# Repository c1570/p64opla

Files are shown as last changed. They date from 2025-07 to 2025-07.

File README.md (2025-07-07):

# p64oPLA - microcontroller-based C64 PLA
https://github.com/c1570/p64opla

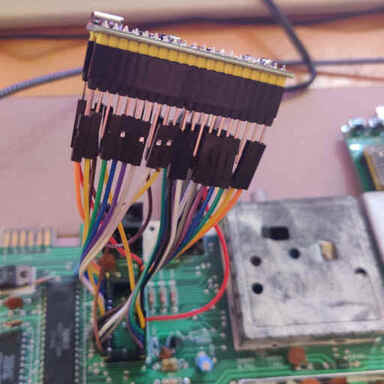
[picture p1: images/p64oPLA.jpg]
p64oPLA prototype


This implements the [Commodore 64](https://en.wikipedia.org/wiki/Commodore_64) [PLA chip](https://www.c64-wiki.com/wiki/PLA_(C64_chip)) using an [RP2040](https://en.wikipedia.org/wiki/RP2040).

This is work in progress.

Pronounced **picoPLA**. Stylizing as 'p64oPLA' makes this better to search for, and it's not really using the Pico (board) anyways.

* cheap
* simple hardware variant can be built using a spare IC socket and a few wires
* extra modes
  * **selftest** (GPIO26 grounded): Checks for shorts on GPIO pins, blinks GPIO num+1 times (GPIO2 = 3 flashes) in case of problems on that line. If no error found, turns LED on for five seconds, off for 100ms, repeat.
  * **offline PLA test** (GPIO26 and GPIO24 grounded): Checks a PLA connected in parallel for errors. LED will blink on errors. If no error found, turns LED on for five seconds, off for 100ms, repeat. Problems as well as **measured CASRAM latency** will be reported in text via USB serial.
  * **live PLA test** (GPIO24 grounded): If connected to a PLA seated in a C64, will check those PLA's outputs while the C64 is powered on. Make sure p64oPLA is not connected via USB then (otherwise current would flow from USB into the C64). LED will light on errors, otherwise the LED will stay off.

* Line delay is very similar to the original PLA.
* In contrast to most replacements, all signal lines exhibit the appropriate signal delay, not only CASRAM.
* There are no glitches (EPROM PLA, I'm looking at you).
* However, this implementation exhibits some delay jitter (signal delay is about 30-42ns).

# Building

* wiring the RP2040 board and PLA
  * connect GPIO0-7 to PLA pins 2-9
  * connect GPIO8-15 to PLA pins 20-27
  * connect GPIO16-19 to PLA pins 10-13
  * connect GPIO20-23 to PLA pins 15-18
  * connect 5V/Vbus to PLA pin 28
  * connect GND to PLA pin 14 and PLA pin 19
  * leave PLA pin 1 unconnected
* note the original Pico board does not expose GPIO23; "RGB LED" RP2040 boards do though (disable the RGB LED there though by unsoldering the "RGB" jumper)

## PCB

Designing a dedicated PCB would be nice at some point...

## Test clips

For the live test mode, you'll want some way to connect 26 wires (PLA pin 19 is not needed then) to the PLA in the C64 reliably which can be arduous.
You can 3D print [dip_clip_28p.stl](/hardware/dip_clip_28p.stl) twice and build an 28 pin DIP test clip from that.
The STL file has been generated from ["DIP IC Test Clip"](https://www.thingiverse.com/thing:4690158/) by Andy Anderson (CC-BY license) using settings `ic_pin_count = 28` and `ic_width = 14`.

# Implementation notes
This simply looks up output values using an array using the CPU cores, overclocked to 400MHz.
Both cores run in parallel, executing the same program, to reduce worst case latency.
They sync automatically because of SRAM lookup contention.

The data word read from the GPIOs represents the RAM address of the byte to look up directly because input overrides are set for upper GPIOs.

No shifting of the output value (to GPIO16 and up) is needed since byte writes to SIO registers are replicated over the full bus width (e.g., writing byte 0x12 actually writes 0x12121212).

## Abandoned PIO/DMA version
A PIO/DMA variant of this was also in testing (similar to [cknave's C64 Pico RAM interface](https://github.com/cknave/c64-pico-ram-interface)):

* reading from GPIOs using a PIO
* DMA the resulting address from the PIO RX FIFO to another DMA channel's read address (and trigger) register
* The other DMA channel fetches the result byte from the lookup table and writes it to another PIO
* Other PIO writes to GPIOs

(One could actually omit using the PIOs but unfortunately SIO GPIO control registers are only available to the CPU cores, not DMA.)

However, this has a rather long latency along these lines:
* 1 cycle input GPIO pad
* 2 cycles input synchronizer
* 1 cycle input PIO
* 4 cycles first DMA pipeline (details: [1](https://forums.raspberrypi.com/viewtopic.php?p=1915671#p1915671) [2](https://forums.raspberrypi.com/viewtopic.php?p=2196725#p2196725) [3](https://forums.raspberrypi.com/viewtopic.php?p=2247708#p2247708))
* 4 cycles second DMA pipeline
* 1 cycle output PIO
* 1 cycle output GPIO pad

Also, there's a lot of jitter, probably because PIO FIFO reads/writes and DMA control writes all go through a single AHB port.

Perhaps RP2350 improves this, but I doubt it.

# License
AGPLv3

In short, this means that...
* proper attribution has to be given
* source has to be made available

In case you don't want to do this (e.g., you want to sell white labeled versions commercially, or not hand out the sources, or similar), commercial licenses are available starting 20€/piece.

# Compiling
```
export PICO_SDK_PATH=...
cmake -DPICO_COPY_TO_RAM=1 .
make -j16
```

## Testing
Use `src/test-p64pla.ts` along with [rp2040js](https://github.com/c1570/rp2040js).

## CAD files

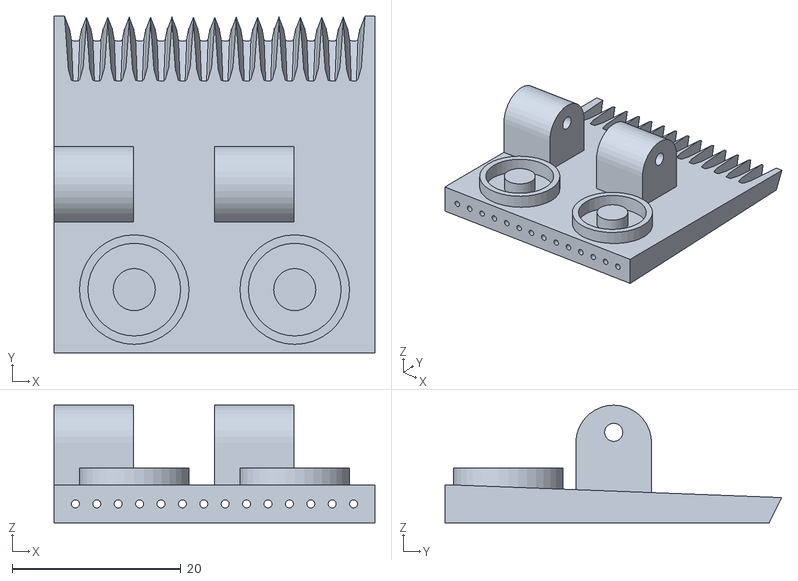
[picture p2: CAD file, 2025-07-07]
hardware/dip_clip_28p.stl
38.1 x 40.0 x 14.0

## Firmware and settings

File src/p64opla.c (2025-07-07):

// p64oPLA - microcontroller-based C64 PLA
// https://github.com/c1570/p64opla
// AGPLv3 licensed

#include <stdio.h>
#include "pico/stdlib.h"
#include "pico/sync.h"
#include "pico/multicore.h"
#include "hardware/pio.h"
#include "hardware/vreg.h"
#include "hardware/clocks.h"
#include "hardware/structs/sio.h"

#include "pla.h"

uint SYS_CLOCK_KHZ = 400000;

const uint LED_PIN = 25;
const uint BUTTON_PIN = 24;
const uint MODE_PIN = 26;

void blink_led(const uint flashes, const uint on_ms, const uint off_ms, const uint after_ms) {
  for(uint i = 1; i <= flashes; i++) {
    gpio_put(LED_PIN, 1);
    busy_wait_us(on_ms * 1000);
    gpio_put(LED_PIN, 0);
    busy_wait_us(off_ms * 1000);
  }
  busy_wait_us(after_ms * 1000);
}

static void selftest(const uint pin_start, const uint pin_end) {
  // short/stuck detection: sets all pins to pullup, shifts one LOW through pins,
  // blinks if more than one pin is low during that
  gpio_put(LED_PIN, 0);
  gpio_set_dir(LED_PIN, GPIO_OUT);
  for(uint pin = pin_start; pin <= pin_end; pin++) {
    gpio_init(pin);
    gpio_set_dir(pin, GPIO_IN);
    gpio_pull_up(pin);
    gpio_put(pin, false);
  }
  const uint32_t mask_our_pins = ((1 << (pin_end + 1)) - 1) - ((1 << pin_start) - 1);
  while(1) {
    bool found_error = false;
    for(uint pin = pin_start; pin <= pin_end; pin++) {
      gpio_set_dir(pin, GPIO_OUT); // set GPIO "pin" low (value has been set above)
      busy_wait_us(1000);
      uint32_t gpios_in = gpio_get_all() & mask_our_pins;
      if(gpios_in != (mask_our_pins - (1 << pin))) {
        // we expected only one GPIO low but don't see that: there's some short
        blink_led(pin + 1, 500, 200, 800); // start signaling with output pin number
        for(uint test = 0; test <= pin_end; test++) {
          if(test != pin) {
            if(!(gpios_in & 1)) blink_led(test + 1, 500, 200, 800); // blink 1 time for GPIO 0, etc.
            found_error = true;
          }
          gpios_in >>= 1;
        }
        busy_wait_us(2000000);
      }
      gpio_set_dir(pin, GPIO_IN);
    }
    if(!found_error) {
      blink_led(1, 5000, 100, 0);
    } else {
      gpio_put(LED_PIN, 0);
      busy_wait_us(4000000);
    }
  }
}

static void platest_live() {
  // live external PLA test: connect p64opla parallel to another PLA in the C64,
  // run this test, and LED will light if the other PLA behaves incorrectly.
  gpio_put(LED_PIN, 0);
  gpio_set_dir(LED_PIN, GPIO_OUT);
  for(uint pin = 0; pin <= 23; pin++) {
    gpio_init(pin);
    gpio_put(pin, 0);
    gpio_set_dir(pin, GPIO_IN);
  }
  uint32_t steady = 0;
  uint32_t gpios_prev = 0;
  while(1) {
    uint32_t gpios = gpio_get_all() & 0x00ffffff;
    if((gpios & 0xffff) != (gpios_prev & 0xffff)) {
      steady = 0;
      gpios_prev = gpios;
      continue;
    }
    if(steady > 2) {
      // if input lines have been steady for a bit, we can assume
      // outputs have settled as well
      uint8_t expected_out = PLA_OUTPUT[gpios & 0xffff];
      if(((gpios >> 16) & 0xff) != expected_out) {
        gpio_put(LED_PIN, 1);
        busy_wait_us(5000000);
      }
      gpio_put(LED_PIN, 0);
    } else {
      steady++;
    }
  }
}

static inline int __attribute__((always_inline)) get_signal_latency(uint trigger_pin, uint measure_pin, bool trigger_on_posedge, bool wait_for_posedge) {
  // set up pin states in PIO before switching GPIO functions to PIO
  pio_sm_set_consecutive_pindirs(pio0, 0, trigger_pin, 1, true);
  pio_sm_set_pins(pio0, 0, (!trigger_on_posedge) << trigger_pin);
  pio_sm_set_consecutive_pindirs(pio0, 0, measure_pin, 1, false);
  // save previous pin functions, then switch functions to PIO
  enum gpio_function func_trigger = gpio_get_function(trigger_pin);
  gpio_set_function(trigger_pin, GPIO_FUNC_PIO0);
  enum gpio_function func_measure = gpio_get_function(measure_pin);
  gpio_set_function(measure_pin, GPIO_FUNC_PIO0);
  busy_wait_us(10); // wait for things to settle

  pio0->instr_mem[0] = pio_encode_set(pio_pins, trigger_on_posedge);
  pio0->instr_mem[1] = pio_encode_in(pio_pins, 1);
  pio_sm_config measure_sm_config = pio_get_default_sm_config();
  sm_config_set_wrap(&measure_sm_config, 1, 1); // loop on IN instruction
  sm_config_set_in_pins(&measure_sm_config, measure_pin);
  sm_config_set_in_shift(&measure_sm_config, false /* true: shift ISR right */,
                         true /* autopush */, 32 /* autopush threshold */);
  sm_config_set_set_pins(&measure_sm_config, trigger_pin, 1);
  sm_config_set_clkdiv(&measure_sm_config, 1);
  pio_sm_init(pio0, 0, 0 /* SM start instruction addr */, &measure_sm_config);
  pio_sm_set_enabled(pio0, 0, true);

  int cycles = 0;
  while(1) {
    uint32_t p = pio_sm_get_blocking(pio0, 0);
    if(!wait_for_posedge) p = ~p;
    if(__builtin_expect(!p, 1)) { // fast path has to be faster than 32 cycles
      cycles += 32;
      if(cycles >> 22) { // timeout after about 10ms
        cycles = -1;
        break;
      }
      continue;
    } else {
      cycles += __builtin_clz(p); // count leading zero bits
      break;
    }
  }

  pio_sm_set_enabled(pio0, 0, false);
  pio_sm_clear_fifos(pio0, 0);
  // restore previous GPIO functions (SIO in this case)
  gpio_set_function(trigger_pin, func_trigger);
  gpio_set_function(measure_pin, func_measure);
  busy_wait_us(2);

  return cycles;
}

static void platest_offline() {
  // external PLA test: connect p64opla parallel to another PLA standalone,
  // run this test, and LED will light if the other PLA behaves incorrectly.
  // one successful test run takes a few milliseconds.
  gpio_put(LED_PIN, 0);
  gpio_set_dir(LED_PIN, GPIO_OUT);
  for(uint pin = 0; pin <= 23; pin++) {
    gpio_init(pin);
    if(pin < 16) {
      gpio_put(pin, 0);
      gpio_set_dir(pin, GPIO_OUT);
      gpio_set_drive_strength(pin, GPIO_DRIVE_STRENGTH_4MA);
    } else {
      gpio_set_dir(pin, GPIO_IN);
    }
  }
  stdio_init_all();
  while(1) {
    gpio_put_masked(0xffff, 0 | (1<<7) | (1<<14)); // $0000 RAM read access, CAS inactive, BA active
    float lat_min = -1;
    float lat_max = -1;
    for(uint i = 0; i < 10; i++) {
      int latency = get_signal_latency(7, 23, false, false); // enable CAS, wait for CASRAM to go active
      if(latency < lat_min || lat_min == -1) lat_min = latency;
      if(latency > lat_max || lat_max == -1) lat_max = latency;
    }
    // at 400MHz, RP2040 pin to pin latency is 5 cycles
    lat_min = lat_min >= 5 ? ((float) lat_min - 5) * (1000000.0 / SYS_CLOCK_KHZ) : -1;
    lat_max = lat_max >= 5 ? ((float) lat_max - 5) * (1000000.0 / SYS_CLOCK_KHZ) : -1;
    if(lat_min >= 0) {
      printf("CASRAM latency: %.1f to %.1f nanoseconds\n", lat_min, lat_max);
    } else {
      printf("Could not measure CASRAM latency\n");
    }

    bool failure = false;
    for(uint i = 0; i < 0x10000; i++) {
      gpio_put_masked(0xffff, i);
      uint8_t expected_out = PLA_OUTPUT[i];
      busy_wait_us(2);
      uint8_t actual_out = (gpio_get_all() >> 16) & 0xff;
      bool correct = actual_out == expected_out;
      if(!correct) {
        printf("Test pattern 0b%016b, expected 0b%08b, got 0b%08b\n", i, expected_out, actual_out);
        failure = true;
        blink_led(5, 150, 150, 200);
      }
    }
    if(!failure) {
      printf("Test passed successfully\n");
      blink_led(1, 5000, 100, 0);
    }
  }
}

void __attribute__((noinline)) __scratch_x("c0") core0() {
  #include "p64opla_loop.inc"
}

void __attribute__((noinline)) __scratch_y("c1") core1() {
  #include "p64opla_loop.inc"
}

int main() {
  // init pins
  for(int pin=0; pin<=29; pin++) {
    gpio_init(pin);
    if(pin <= 15) {
      gpio_set_dir(pin, GPIO_IN);
      // gpio_pull_up(pin); // debugging only
    } else if(pin <= 23) {
      gpio_set_dir(pin, GPIO_OUT);
      gpio_set_drive_strength(pin, GPIO_DRIVE_STRENGTH_4MA);
      gpio_set_slew_rate(pin, GPIO_SLEW_RATE_SLOW);
    }
  }

  // init LED
  gpio_init(LED_PIN);
  gpio_set_dir(LED_PIN, GPIO_OUT);
  gpio_put(LED_PIN, 1);

  // init button
  gpio_init(BUTTON_PIN);
  gpio_set_dir(BUTTON_PIN, GPIO_IN);
  gpio_pull_up(BUTTON_PIN);

  // init mode pin
  gpio_init(MODE_PIN);
  gpio_set_dir(MODE_PIN, GPIO_IN);
  gpio_pull_up(MODE_PIN);

  // set system clock
  vreg_set_voltage(VREG_VOLTAGE_1_30);
  busy_wait_us(10000);
  set_sys_clock_khz(SYS_CLOCK_KHZ, true);
  gpio_put(LED_PIN, 0);
  gpio_set_dir(LED_PIN, GPIO_IN);
  busy_wait_us(10000); // core0 likes to crash on RP2350 otherwise

  // if mode pin is grounded, allow tests that set input lines
  if(!gpio_get(MODE_PIN)) {
    if(gpio_get(BUTTON_PIN)) {
      selftest(0, 23); // only mode pin grounded: do selftest
    } else {
      platest_offline(); // mode pin grounded and button pressed: external PLA offline test
    }
  } else {
    // do live external PLA test if (only) button pressed on startup
    if(!gpio_get(BUTTON_PIN)) platest_live();
  }

  // set upper GPIO input overrides so that the PIO reading the GPIOs
  // just produces the appropriate address of the PLA_OUTPUT entry
  for(int pin=16; pin<=29; pin++) {
    gpio_set_input_enabled(pin, false);
    gpio_set_inover(pin, ((((uint32_t) PLA_OUTPUT) >> pin) & 1) ? GPIO_OVERRIDE_HIGH : GPIO_OVERRIDE_LOW);
  }

  multicore_launch_core1(core1);
  core0();
}
